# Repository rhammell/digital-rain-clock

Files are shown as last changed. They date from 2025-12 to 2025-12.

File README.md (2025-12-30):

# digital-rain-clock
This repository contains the Arduino code and 3D models required to build a desktop clock that features animated digital rain.

Read the [project guide](https://www.hackster.io/rhammell/digital-rain-clock-inspired-by-the-matrix-49dede) on Hackster.io for a complete project description and build tutorial.

# Project Description
<p align="center">
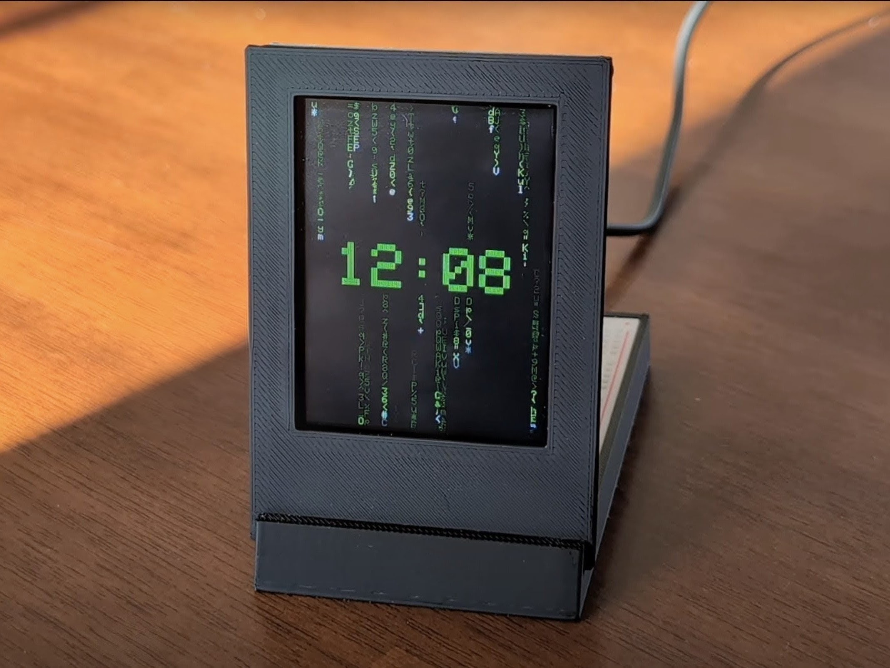
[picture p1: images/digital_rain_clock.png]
Digital Rain Clock
  
</p>

Digital rain, or "Matrix Code", is an animated visualization that features columns of text characters that continuously rain down to create a captivating, streaming motion.

This project demonstrates how to build a desktop clock that displays the time against a digital rain background. The digital rain clock is designed as a functional desktop accessory, combining practical timekeeping with a dynamic, eye-catching visualization. Users can enjoy ambient visuals of the rain and use touch interactions to set the time and change its color.

## Features
It features a touchscreen display and integrated control electronics mounted to a custom 3D-printed stand. These electronics are intentionally exposed behind the screen to emphasize a maker-style aesthetic.

*   **Digital Rain Animation**: Once powered via USB, the clock renders a digital rain animation consisting of trails of randomized characters cascading vertically down the screen at varying speeds.
*   **Time Overlay**: At the start of each minute, the current time is overlaid at the center of the screen. After several seconds, the digits gradually dissolve as streaks of digital rain overwrite them. Tapping the center of the screen brings the time back into view on demand.
*   **Touch Controls**:
    *   **Time Adjustment**: Adjusting the current time is done by tapping the top-right corner to open a menu with touch controls for changing the hour and minute values. Tapping the same corner again closes the menu and displays the updated time.
    *   **Color Customization**: The color of the digital rain and time can be updated by tapping the bottom-left corner of the screen. Each tap cycles the interface through green, red, blue, yellow, and purple color schemes.

## Hardware Components
The physical build of the digital clock consists of multiple electronic components and a 3D printed structural stand.

*   **Display**: An **Adafruit 2.8" TFT breakout board** serves as the display that shows the clock face. The board includes a 240x320 pixel full-color display and capacitive touchscreen that detects user touches.
*   **Processor**: An **Arduino Nano ESP32** acts as the clock's primary processor and power source. It connects to the display via the EYESPI breakout and executes custom firmware that manages the rain animation, maintains clock timing, and handles touchscreen input.
*   **Interconnect**: **EYESPI** is a connection standard developed by Adafruit to simplify the wiring of its displays. This standard is utilized by connecting the TFT to an **Adafruit EYESPI breakout board** via an 18 pin FPC.
*   **Stand**: The Nano and EYESPI breakout are wired together on a breadboard that sits within the stand base, while the display is mounted to the upright stand face. The stand face pressure-fits within a slot on the base.

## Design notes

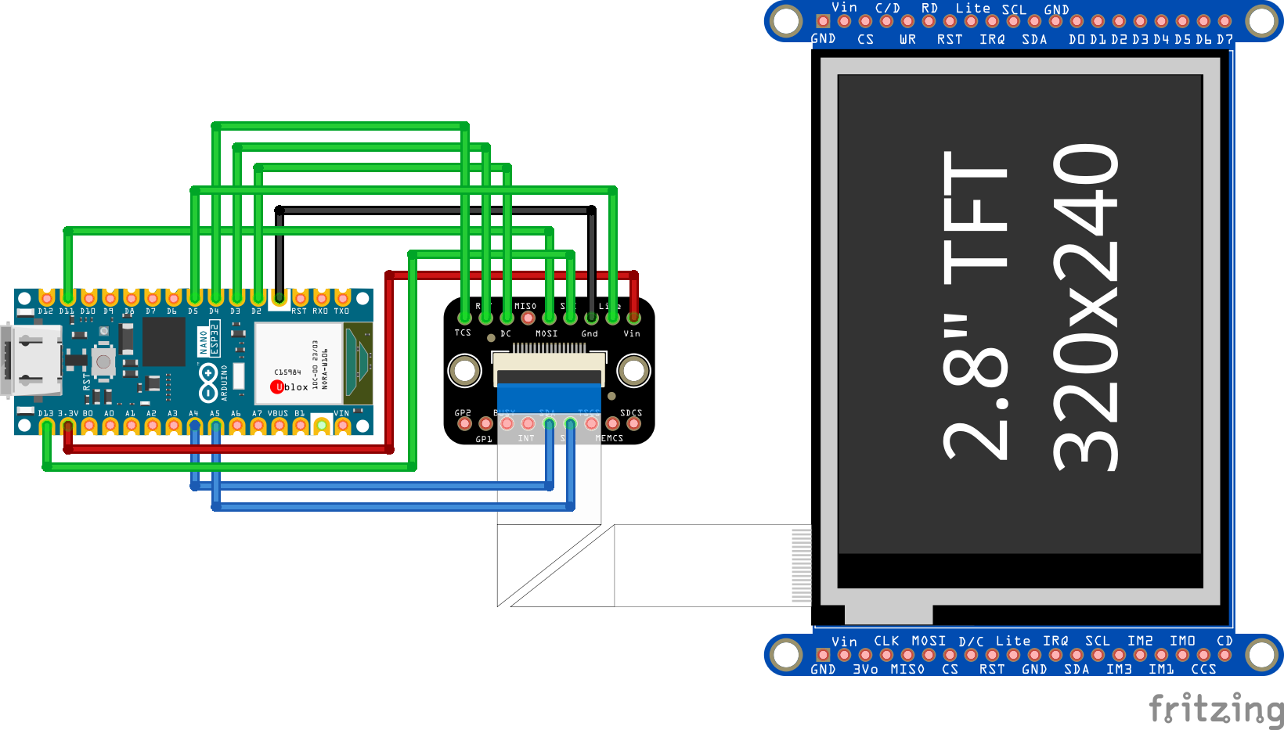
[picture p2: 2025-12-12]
images/schematic.png

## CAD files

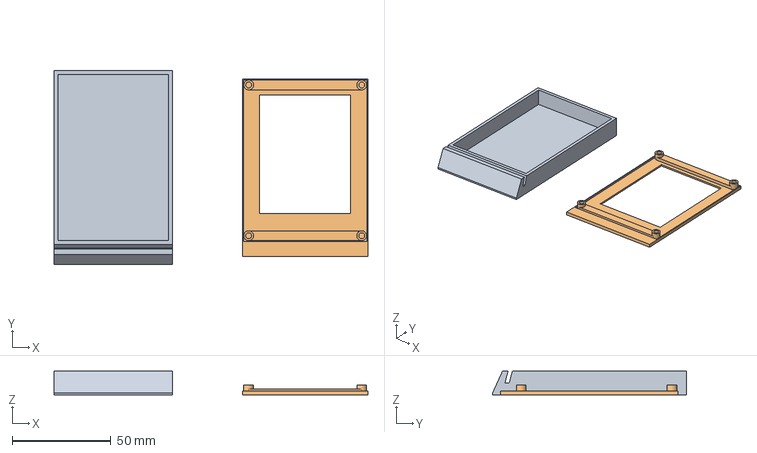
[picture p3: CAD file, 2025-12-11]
hardware/source/ClockDesign.FCStd
158.7 x 98.0 x 12.0 mm
Base
Display

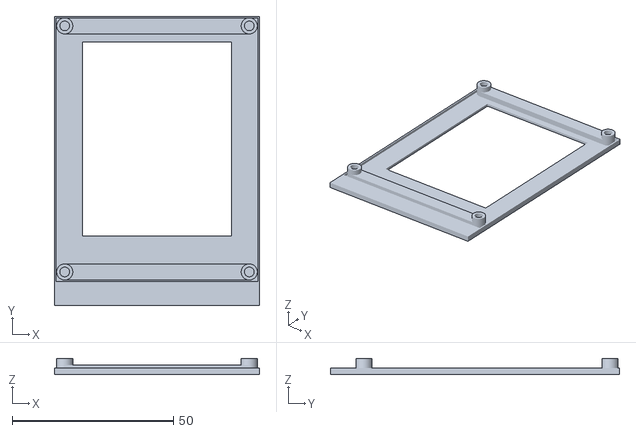
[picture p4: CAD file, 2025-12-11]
hardware/stl/display.stl
63.5 x 89.5 x 5.00

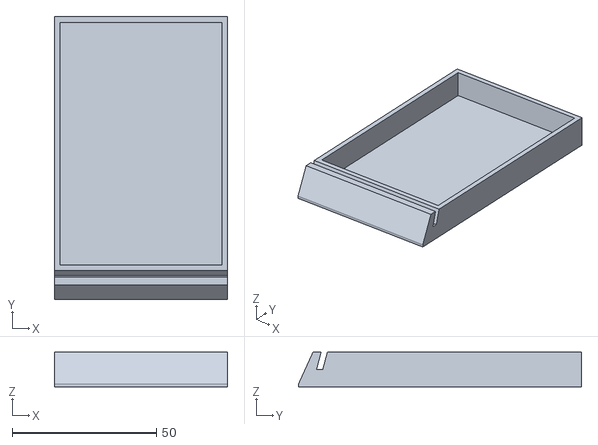
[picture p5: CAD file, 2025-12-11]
hardware/stl/base.stl
60.0 x 98.0 x 12.0

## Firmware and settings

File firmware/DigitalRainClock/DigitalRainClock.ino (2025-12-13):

#include <Wire.h>
#include <Adafruit_FT6206.h>
#include <Adafruit_GFX.h>
#include <Adafruit_ILI9341.h> 
#include <ESP32Time.h>

// TFT Pins for Nano ESP32
// D11 -> MOSI
// D13 -> SCK
// A4 -> SDA
// A5 -> SCL
#define TFT_DC   2
#define TFT_RST  3
#define TFT_CS   4
#define TFT_LED  5

// Initialize the display object
Adafruit_ILI9341 tft = Adafruit_ILI9341(TFT_CS, TFT_DC, TFT_RST);

// Initialize the capacitive touchscreen object
Adafruit_FT6206 ctp;

// Screen dimensions - portrait
const int SCREEN_W = 240;
const int SCREEN_H = 320;

// Text scale
const int TEXT_SCALE = 1;

// Font pixel width and height
const int FONT_PIXEL_W = 6;
const int FONT_PIXEL_H = 8;
const int CHAR_W = FONT_PIXEL_W * TEXT_SCALE;
const int CHAR_H = FONT_PIXEL_H * TEXT_SCALE;

// Number of columns and rows
const int NUM_COLS = SCREEN_W / CHAR_W;
const int NUM_ROWS = SCREEN_H / CHAR_H;

// Column-specific tail length range (in rows)
const int MIN_TAIL_LEN = 14;
const int MAX_TAIL_LEN = 20;

// Global speed range (ms per row step)
const uint16_t MIN_INTERVAL = 60;
const uint16_t MAX_INTERVAL = 160;

// Clock overlay parameters
const int  TIME_TEXT_LENGTH          = 5;
const uint16_t TIME_OVERLAY_DURATION_MS = 3600;
const int TIME_TEXT_SIZE        = 6;
char timeText[TIME_TEXT_LENGTH + 1] = "12:00";

// Column state
struct ColumnState {
  int headRow;
  uint16_t intervalMs;
  uint32_t lastUpdateMs;
  uint8_t tailLength;
};

// Array of column states
ColumnState columns[NUM_COLS];

// Character buffer for trail characters
char glyphs[NUM_COLS][NUM_ROWS];

// Colors for rain (head + trail levels) and background
uint16_t matrixHeadColor;
uint16_t matrixTrailBright;
uint16_t matrixTrailDim;
uint16_t matrixTrailDark;
uint16_t matrixBgColor;

// Real-time clock
ESP32Time rtc;

// Last displayed minute
int lastDisplayedMinute = -1;

// Color scheme struct
struct ColorScheme {
  uint16_t head;
  uint16_t bright;
  uint16_t dim;
  uint16_t dark;
};

// Number of color schemes
const uint8_t NUM_COLOR_SCHEMES = 5;

// Array of color schemes
ColorScheme colorSchemes[NUM_COLOR_SCHEMES];

// Current color scheme
uint8_t currentColorScheme = 0;

// Color toggle region
const int COLOR_TOGGLE_REGION_W = 60;
const int COLOR_TOGGLE_REGION_H = 60;
const uint16_t COLOR_TOGGLE_DEBOUNCE_MS = 250;
uint32_t lastColorToggleMs = 0;

// Brightness toggle region (upper right)
const int BRIGHTNESS_TOGGLE_REGION_W = 60;
const int BRIGHTNESS_TOGGLE_REGION_H = 60;
const uint16_t BRIGHTNESS_TOGGLE_DEBOUNCE_MS = 250;
uint32_t lastBrightnessToggleMs = 0;

// Brightness levels
const uint8_t BRIGHTNESS_LEVELS[] = {20, 40, 60, 80, 100};
const uint8_t NUM_BRIGHTNESS_LEVELS = sizeof(BRIGHTNESS_LEVELS) / sizeof(BRIGHTNESS_LEVELS[0]);

// Current brightness index - default to 100%
uint8_t currentBrightnessIndex = NUM_BRIGHTNESS_LEVELS - 1;

// Settings toggle region
const int SETTINGS_TOGGLE_REGION_W = 60;
const int SETTINGS_TOGGLE_REGION_H = 60;
const uint16_t SETTINGS_TOGGLE_DEBOUNCE_MS = 250;
uint32_t lastSettingsToggleMs = 0;
const uint16_t SETTINGS_BUTTON_DEBOUNCE_MS = 200;
uint32_t lastSettingsButtonMs = 0;

// Time overlay state struct
struct TimeOverlay {
  bool active;
  uint32_t startMs;
  uint32_t endMs;
  bool needsDraw;
};

// Time overlay struct
TimeOverlay overlay = { false, 0, 0, false };

// Settings menu state
bool settingsActive = false;
int settingsHour = 12;
int settingsMinute = 0;

// Button region struct
struct ButtonRegion {
  int x;
  int y;
  int w;
  int h;
};

// Button regions
ButtonRegion hourUpButton = {0};
ButtonRegion hourDownButton = {0};
ButtonRegion minuteUpButton = {0};
ButtonRegion minuteDownButton = {0};

// Settings time display region
int settingsTimeDisplayX = 0;
int settingsTimeDisplayY = 0;
int settingsTimeDisplayW = 0;
int settingsTimeDisplayH = 0;

// Settings menu constants
const int SETTINGS_PANEL_MARGIN = 10;
const int SETTINGS_BUTTON_W = 80;
const int SETTINGS_BUTTON_H = 40;
const int SETTINGS_BUTTON_SPACING = 10;
const int SETTINGS_LABEL_OFFSET = 15;
const int SETTINGS_TIME_TEXT_SIZE = 3;
const int SETTINGS_TITLE_TEXT_SIZE = 2;
const int SETTINGS_TITLE_OFFSET_Y = 25;
const int SETTINGS_BUTTON_VERTICAL_OFFSET = 10;
const int SETTINGS_LABEL_OFFSET_ADJUST = 5;

// Global overlay area bounds 
int overlayAreaX, overlayAreaY, overlayAreaW, overlayAreaH;
int startOverlayCol, endOverlayCol; 

// Function prototypes
char randomGlyph();
void initColumns();
void resetColumn(int col);
void updateMatrixRain();
void handleTouch();
void updateTimeOverlay();
void calcTimeOverlayArea();
void drawRainChar(int x, int row, char ch, uint16_t color);
void initColorSchemes();
void applyColorScheme(uint8_t index);
void cycleColorScheme();
bool isColorToggleTouch(int x, int y);
bool isSettingsToggleTouch(int x, int y);
void enterSettingsMenu();
void exitSettingsMenu();
void drawSettingsMenu();
void startTimeOverlay(uint32_t now);
void updateTimeTextFromClock();
void checkMinuteTick();
void handleSettingsTouch(int x, int y);
void drawTimeAdjustControls();
void updateSettingsTimeDisplay();
void drawButton(int x, int y, int w, int h, const char *label);
bool pointInRect(int x, int y, int rx, int ry, int rw, int rh);
bool isBrightnessToggleTouch(int x, int y);
void cycleBrightness();
void applyBrightnessIndex(uint8_t idx);

void setup() {
  // Initialize serial communication
  Serial.begin(115200);
  Serial.println("Starting TFT and Touch Initialization...");
 
  // Backlight control (PWM for brightness)
  pinMode(TFT_LED, OUTPUT);
  applyBrightnessIndex(currentBrightnessIndex);

  // TFT Display Setup
  tft.begin();
  tft.fillScreen(ILI9341_BLACK);

  // Touchscreen Setup
  if (!ctp.begin()) {
    // Display error message if touchscreen initialization fails
    Serial.println("ERROR: Couldn't start FT6206 touchscreen controller.");
    tft.fillScreen(ILI9341_BLACK);
    tft.setTextSize(2);
    tft.setTextWrap(true);
    tft.setTextColor(ILI9341_GREEN, ILI9341_BLACK);
    tft.setCursor(10, 40);
    tft.println("Touchscreen error");
    tft.setTextSize(1);
    tft.println();
    tft.println("FT6206 not detected.");
    tft.println("Check wiring/power,");
    tft.println("then reset board.");

    // Halt: no further action taken
    while (1) {
      delay(1000);
    }
  }
  Serial.println("FT6206 touchscreen initialized successfully.");

  // Set up text parameters for digital rain
  tft.setTextSize(TEXT_SCALE);
  tft.setTextWrap(false);

  // Initialize color schemes and apply the first color scheme
  initColorSchemes();
  applyColorScheme(0);

  // Set the background color
  matrixBgColor = ILI9341_BLACK;
  tft.fillScreen(matrixBgColor);

  // Set initial time
  rtc.setTime(0, 0, 12, 1, 1, 2024);
  updateTimeTextFromClock();

  // Seed random number generator
  randomSeed(analogRead(A0));

  // Initialize digital rain column states and glyphs
  initColumns();
  
  // Pre-calculate the time overlay area dimensions
  calcTimeOverlayArea();

  // Initialize time overlay
  overlay.active = false;
  lastDisplayedMinute = rtc.getMinute();
  startTimeOverlay(millis());
}

void loop() {
  // Handle touch events 
  handleTouch();    

  // Check if the minute has changed and update the time text if it has
  checkMinuteTick();

  // If settings are active, do not update the time overlay
  if (settingsActive) {
    return;
  }

  // Update digital rain characters
  updateMatrixRain();

  // Update time overlay
  updateTimeOverlay(); 
}


// Initialize digital rain columns
void initColumns() {
  // Pre-fill glyphs
  for (int col = 0; col < NUM_COLS; col++) {
    for (int row = 0; row < NUM_ROWS; row++) {
      glyphs[col][row] = randomGlyph();
    }
  }

  // Initialize each column's state
  for (int col = 0; col < NUM_COLS; col++) {
    resetColumn(col);
    // Start headRow somewhere above the visible area so streams "fall in"
    columns[col].headRow = random(-NUM_ROWS, 0);
  }
}

// Reset a digital rain column
void resetColumn(int col) {
  // Get the column state
  ColumnState &c = columns[col];

  // Generate a random tail length for the column
  c.tailLength = random(MIN_TAIL_LEN, MAX_TAIL_LEN + 1);  // inclusive range

  // Map tail length to speed: shorter tail => smaller interval => faster, longer tail => larger interval => slower
  int tailSpan = MAX_TAIL_LEN - MIN_TAIL_LEN;
  if (tailSpan < 1) tailSpan = 1; // Avoid division by zero

  // Generate a base interval for the column
  uint16_t baseInterval = MIN_INTERVAL +
    (uint16_t)((long)(c.tailLength - MIN_TAIL_LEN) * (MAX_INTERVAL - MIN_INTERVAL) / tailSpan);

  // Add a little jitter so similar tails aren't perfectly identical to avoid repetition
  int16_t jitter = random(-15, 16); // -15 .. +15
  int32_t intervalWithJitter = (int32_t)baseInterval + jitter;
  if (intervalWithJitter < 20) intervalWithJitter = 20; // Clamp to sane minimum to avoid too fast falling

  // Set the interval for the column
  c.intervalMs   = (uint16_t)intervalWithJitter;
  c.lastUpdateMs = millis();

  // Set the last update time for the column
  c.lastUpdateMs = millis();
}

// Generate a random glyph
char randomGlyph() {
  // Random printable ASCII; tweak range if you want other characters
  return (char)random(33, 126); // '!' to '~'
}

// Calculate the time overlay area once
void calcTimeOverlayArea() {
  int charPixelW = FONT_PIXEL_W * TIME_TEXT_SIZE;
  int charPixelH = FONT_PIXEL_H * TIME_TEXT_SIZE;
  int textPixelW = TIME_TEXT_LENGTH * charPixelW;

  // Calculate the padding size: 1 font-pixel row + 2 extra pixels to avoid text being cut off
  int vPad = (1 * TIME_TEXT_SIZE) + 2;

  // Calculate the x position of the time overlay
  int tx = (SCREEN_W - textPixelW) / 2;
  if (tx < 0) tx = 0;
  
  // Calculate the y position of the time overlay
  int ty = (SCREEN_H - charPixelH) / 2;
  if (ty < 0) ty = 0;

  // Store the time overlay area dimensions globally
  overlayAreaX = tx;
  overlayAreaY = ty - vPad;
  overlayAreaW = textPixelW - 1;
  overlayAreaH = charPixelH + vPad; 

  // Calculate which columns intersect with this X-range for optimization
  // Column width is CHAR_W
  startOverlayCol = overlayAreaX / CHAR_W;
  endOverlayCol   = (overlayAreaX + overlayAreaW) / CHAR_W;
}

// Initialize color schemes
void initColorSchemes() {
  // Color scheme 0: Green
  colorSchemes[0] = {
    ILI9341_WHITE,
    ILI9341_GREEN,
    ILI9341_DARKGREEN,
    tft.color565(0, 70, 0)
  };

  // Color scheme 1: Red
  colorSchemes[1] = {
    tft.color565(255, 220, 220),
    ILI9341_RED,
    tft.color565(120, 0, 0),
    tft.color565(60, 0, 0)
  };

  // Color scheme 2: Blue
  colorSchemes[2] = {
    tft.color565(220, 240, 255),
    tft.color565(0, 180, 255),
    tft.color565(0, 90, 170),
    tft.color565(0, 40, 90)
  };

  // Color scheme 3: Yellow
  colorSchemes[3] = {
    tft.color565(255, 255, 210),
    ILI9341_YELLOW,
    tft.color565(180, 140, 0),
    tft.color565(120, 90, 0)
  };

  // Color scheme 4: Purple
  colorSchemes[4] = {
    tft.color565(240, 210, 255),
    ILI9341_MAGENTA,
    tft.color565(120, 0, 150),
    tft.color565(70, 0, 90)
  };
}

// Apply a color scheme
void applyColorScheme(uint8_t index) {
  // If the index is out of bounds, set it to 0
  if (index >= NUM_COLOR_SCHEMES) {
    index = 0;
  }

  // Set the current color scheme
  currentColorScheme = index;

  // Set the color scheme colors to the global variables
  matrixHeadColor   = colorSchemes[index].head;
  matrixTrailBright = colorSchemes[index].bright;
  matrixTrailDim    = colorSchemes[index].dim;
  matrixTrailDark   = colorSchemes[index].dark;
}

// Cycle through the color schemes
void cycleColorScheme() {
  uint8_t next = (currentColorScheme + 1) % NUM_COLOR_SCHEMES;
  applyColorScheme(next);
  if (overlay.active) {
    overlay.needsDraw = true;
  }
}

// Check if the color toggle is touched
bool isColorToggleTouch(int x, int y) {
  return (x >= (SCREEN_W - COLOR_TOGGLE_REGION_W)) &&
         (y >= (SCREEN_H - COLOR_TOGGLE_REGION_H));
}

// Check if the settings toggle is touched
bool isSettingsToggleTouch(int x, int y) {
  return (x <= SETTINGS_TOGGLE_REGION_W) && (y <= SETTINGS_TOGGLE_REGION_H);
}

// Enter the settings menu
void enterSettingsMenu() {
  settingsActive = true;
  settingsHour = rtc.getHour(true);
  settingsMinute = rtc.getMinute();
  tft.fillScreen(matrixBgColor);
  drawSettingsMenu();
}

// Exit the settings menu
void exitSettingsMenu() {
  // Set the settings active flag to false
  settingsActive = false;

  // Get the current time
  int currentYear = rtc.getYear();
  int currentMonth = rtc.getMonth() + 1; // Month is 0-11, so add 1
  int currentDay = rtc.getDay();

  // Set the time to the current time
  rtc.setTime(0, settingsMinute, settingsHour, currentDay, currentMonth, currentYear);
  lastDisplayedMinute = settingsMinute;
  updateTimeTextFromClock();

  // Fill the screen with the background color
  tft.fillScreen(matrixBgColor);
  initColumns();

  // Reset the time overlay
  overlay.active = false;
  overlay.needsDraw = false;

  // Start the time overlay
  startTimeOverlay(millis());
}

// Draw the settings menu
void drawSettingsMenu() {
  // Set the text size and wrap and color
  tft.setTextSize(SETTINGS_TITLE_TEXT_SIZE);
  tft.setTextWrap(true);
  tft.setTextColor(matrixTrailBright, matrixBgColor);

  // Calculate the panel x, y, width and height
  int panelX = SETTINGS_PANEL_MARGIN;
  int panelY = SETTINGS_PANEL_MARGIN;
  int panelW = SCREEN_W - (SETTINGS_PANEL_MARGIN * 2);
  int panelH = SCREEN_H - (SETTINGS_PANEL_MARGIN * 2);

  // Draw the panel
  tft.drawRect(panelX, panelY, panelW, panelH, matrixTrailBright);

  // Draw the title
  const char *title = "Current Time";
  int titleWidth = strlen(title) * FONT_PIXEL_W * SETTINGS_TITLE_TEXT_SIZE;
  int titleX = panelX + (panelW - titleWidth) / 2;
  int titleY = panelY + SETTINGS_TITLE_OFFSET_Y;
  tft.setCursor(titleX, titleY);
  tft.println(title);

  // Draw the time adjust controls
  drawTimeAdjustControls();
}


// Draw the time adjust controls
void drawTimeAdjustControls() {
  // Calculate the panel x, y, width and height
  int panelX = SETTINGS_PANEL_MARGIN;
  int panelY = SETTINGS_PANEL_MARGIN;
  int panelW = SCREEN_W - (SETTINGS_PANEL_MARGIN * 2);

  // Calculate the time display x, y, width and height
  settingsTimeDisplayX = panelX + 20;
  settingsTimeDisplayY = panelY + 65;
  settingsTimeDisplayW = panelW - 40;
  settingsTimeDisplayH = 60;

  // Draw the time display
  tft.drawRect(settingsTimeDisplayX, settingsTimeDisplayY, settingsTimeDisplayW, settingsTimeDisplayH, matrixTrailBright);
  updateSettingsTimeDisplay();

  // Calculate the controls top
  int controlsTop = settingsTimeDisplayY + settingsTimeDisplayH + 30 + SETTINGS_LABEL_OFFSET_ADJUST;

  // Calculate the hour column x and minute column x
  int hourColumnX = panelX + 30;
  int minuteColumnX = panelX + panelW - SETTINGS_BUTTON_W - 30;

  // Set the text size
  tft.setTextSize(2);

  // Draw the hour label and minute label
  const char *hourLabel = "Hour";
  const char *minuteLabel = "Minute";
  int hourLabelWidth = strlen(hourLabel) * FONT_PIXEL_W * 2;
  int minuteLabelWidth = strlen(minuteLabel) * FONT_PIXEL_W * 2;

  // Calculate the hour label x and minute label x
  int hourLabelX = hourColumnX + (SETTINGS_BUTTON_W - hourLabelWidth) / 2;
  int minuteLabelX = minuteColumnX + (SETTINGS_BUTTON_W - minuteLabelWidth) / 2;

  // Calculate the label y
  int labelY = controlsTop - SETTINGS_LABEL_OFFSET;

  // Draw the hour label and minute label
  tft.setCursor(hourLabelX, labelY);
  tft.println(hourLabel);
  tft.setCursor(minuteLabelX, labelY);
  tft.println(minuteLabel);

  // Calculate the button top
  int buttonTop = controlsTop + SETTINGS_BUTTON_VERTICAL_OFFSET + SETTINGS_LABEL_OFFSET_ADJUST;

  // Calculate the hour up button x, y, width and height
  hourUpButton = { hourColumnX, buttonTop, SETTINGS_BUTTON_W, SETTINGS_BUTTON_H };
  hourDownButton = { hourColumnX, buttonTop + SETTINGS_BUTTON_H + SETTINGS_BUTTON_SPACING, SETTINGS_BUTTON_W, SETTINGS_BUTTON_H };

  // Calculate the minute up button x, y, width and height
  minuteUpButton = { minuteColumnX, buttonTop, SETTINGS_BUTTON_W, SETTINGS_BUTTON_H };
  minuteDownButton = { minuteColumnX, buttonTop + SETTINGS_BUTTON_H + SETTINGS_BUTTON_SPACING, SETTINGS_BUTTON_W, SETTINGS_BUTTON_H };

  // Draw the hour up button, hour down button, minute up button and minute down button
  drawButton(hourUpButton.x, hourUpButton.y, hourUpButton.w, hourUpButton.h, "+");
  drawButton(hourDownButton.x, hourDownButton.y, hourDownButton.w, hourDownButton.h, "-");
  drawButton(minuteUpButton.x, minuteUpButton.y, minuteUpButton.w, minuteUpButton.h, "+");
  drawButton(minuteDownButton.x, minuteDownButton.y, minuteDownButton.w, minuteDownButton.h, "-");
}

// Update the settings time display
void updateSettingsTimeDisplay() {
  // If the time display width or height is 0, return
  if (settingsTimeDisplayW == 0 || settingsTimeDisplayH == 0) {
    return;
  }

  // Fill the time display with the background color
  tft.fillRect(settingsTimeDisplayX + 1, settingsTimeDisplayY + 1,
               settingsTimeDisplayW - 2, settingsTimeDisplayH - 2, matrixBgColor);

  // Create a buffer for the time display
  char buffer[6];
  snprintf(buffer, sizeof(buffer), "%02d:%02d", settingsHour, settingsMinute);

  // Calculate the text width and height
  int textWidth = strlen(buffer) * FONT_PIXEL_W * SETTINGS_TIME_TEXT_SIZE;
  int textHeight = FONT_PIXEL_H * SETTINGS_TIME_TEXT_SIZE;

  // Calculate the cursor x and y
  int cursorX = settingsTimeDisplayX + (settingsTimeDisplayW - textWidth) / 2;
  int cursorY = settingsTimeDisplayY + (settingsTimeDisplayH - textHeight) / 2;

  // Set the text size and color
  tft.setTextSize(SETTINGS_TIME_TEXT_SIZE);
  tft.setTextColor(matrixTrailBright, matrixBgColor);
  tft.setCursor(cursorX, cursorY);

  // Print the time display
  tft.print(buffer);
}

// Draw a button
void drawButton(int x, int y, int w, int h, const char *label) {
  // Draw the button rectangle with the trail bright color
  tft.drawRect(x, y, w, h, matrixTrailBright);
  tft.fillRect(x + 1, y + 1, w - 2, h - 2, matrixBgColor);

  // Calculate the text width and height and cursor x and y
  int textWidth = strlen(label) * FONT_PIXEL_W * 2;
  int textHeight = FONT_PIXEL_H * 2;
  int cursorX = x + (w - textWidth) / 2;
  int cursorY = y + (h - textHeight) / 2;

  // Draw button text
  tft.setTextSize(2);
  tft.setTextColor(matrixTrailBright, matrixBgColor);
  tft.setCursor(cursorX, cursorY);
  tft.print(label);
}

// Check if a point is in a rectangle
bool pointInRect(int x, int y, int rx, int ry, int rw, int rh) {
  return (x >= rx && x <= rx + rw && y >= ry && y <= ry + rh);
}

// Brightness toggle check (upper right region)
bool isBrightnessToggleTouch(int x, int y) {
  return (x >= (SCREEN_W - BRIGHTNESS_TOGGLE_REGION_W)) &&
         (y <= BRIGHTNESS_TOGGLE_REGION_H);
}

// Apply brightness by index into BRIGHTNESS_LEVELS
void applyBrightnessIndex(uint8_t idx) {
  if (idx >= NUM_BRIGHTNESS_LEVELS) {
    idx = NUM_BRIGHTNESS_LEVELS - 1;
  }
  currentBrightnessIndex = idx;
  uint8_t percent = BRIGHTNESS_LEVELS[currentBrightnessIndex];
  uint16_t duty = (uint16_t)percent * 255 / 100;
  analogWrite(TFT_LED, duty);
}

// Cycle brightness to the next preset level
void cycleBrightness() {
  uint8_t next = (currentBrightnessIndex + 1) % NUM_BRIGHTNESS_LEVELS;
  applyBrightnessIndex(next);
}

// Handle settings touch
void handleSettingsTouch(int x, int y) {
  // Get the current time
  uint32_t now = millis();

  // If the last settings button press was less than the debounce time, return
  if (now - lastSettingsButtonMs < SETTINGS_BUTTON_DEBOUNCE_MS) {
    return;
  }

  // Set the updated flag to false
  bool updated = false;

  // Check if the touch is in the hour up button
  if (pointInRect(x, y, hourUpButton.x, hourUpButton.y, hourUpButton.w, hourUpButton.h)) {
    // Increment the hour
    settingsHour = (settingsHour + 1) % 24;
    updated = true;
  } else if (pointInRect(x, y, hourDownButton.x, hourDownButton.y, hourDownButton.w, hourDownButton.h)) {
    // Decrement the hour
    settingsHour = (settingsHour - 1);
    if (settingsHour < 0) settingsHour = 23;
    updated = true;
  } else if (pointInRect(x, y, minuteUpButton.x, minuteUpButton.y, minuteUpButton.w, minuteUpButton.h)) {
    // Increment the minute
    settingsMinute = (settingsMinute + 1) % 60;
    updated = true;
  } else if (pointInRect(x, y, minuteDownButton.x, minuteDownButton.y, minuteDownButton.w, minuteDownButton.h)) {
    // Decrement the minute
    settingsMinute = (settingsMinute - 1);
    if (settingsMinute < 0) settingsMinute = 59;
    updated = true;
  }

  // If the updated flag is true, update the settings time display and set the last settings button press time
  if (updated) {
    updateSettingsTimeDisplay();
    lastSettingsButtonMs = now;
  }
}

// Check if a rain cell overlaps the overlay text box
bool isOverlayArea(int col, int y, int h) {
  // If the overlay is not active, return false
  if (!overlay.active) return false;

  // Fast Check: Is this column even near the text?
  if (col < startOverlayCol || col > endOverlayCol) return false;

  // Precise Check: Y-coordinate overlap
  return (y < overlayAreaY + overlayAreaH && y + h > overlayAreaY);
}

// Draw a rain character
void drawRainChar(int col, int row, char ch, uint16_t color) {
  // If the row is out of bounds, return
  if (row < 0 || row >= NUM_ROWS) return;

  // Calculate the x and y
  int x = col * CHAR_W;
  int y = row * CHAR_H;

  // Check if the rain cell overlaps the overlay text box
  if (isOverlayArea(col, y, CHAR_H)) return;

  // Draw the rain character
  tft.setCursor(x, y);
  tft.setTextColor(color, matrixBgColor);
  tft.write(ch);
}
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

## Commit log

2025-12-09 Update DigitalRainClock.ino to include I2C pin definitions for SDA and SCL
2025-12-11 Add CAD and STL files for 3D printable stand; Update gitignore
    [ClockDesign.FCStd, base.stl, display.stl]
2025-12-12 Add schematic image
2025-12-13 Fix portrait mode dimensions; Set screen background color
    [DigitalRainClock.ino]
